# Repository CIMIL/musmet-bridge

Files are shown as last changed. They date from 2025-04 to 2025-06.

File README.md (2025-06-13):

# MUSMET MIDI Bridge
(**MUS**ical **MET**averse **MIDI** **Bridge**)

Hardware and software solution that lets you use your MIDI devices in a _**Musical Metaverse**_. Connect any class-compliant MIDI device and map its MIDI input into OSC messages. 
These OSC messages can then be sent to a VR/XR musical ecosystem (e.g., PatchWorld) or other compatible platforms.

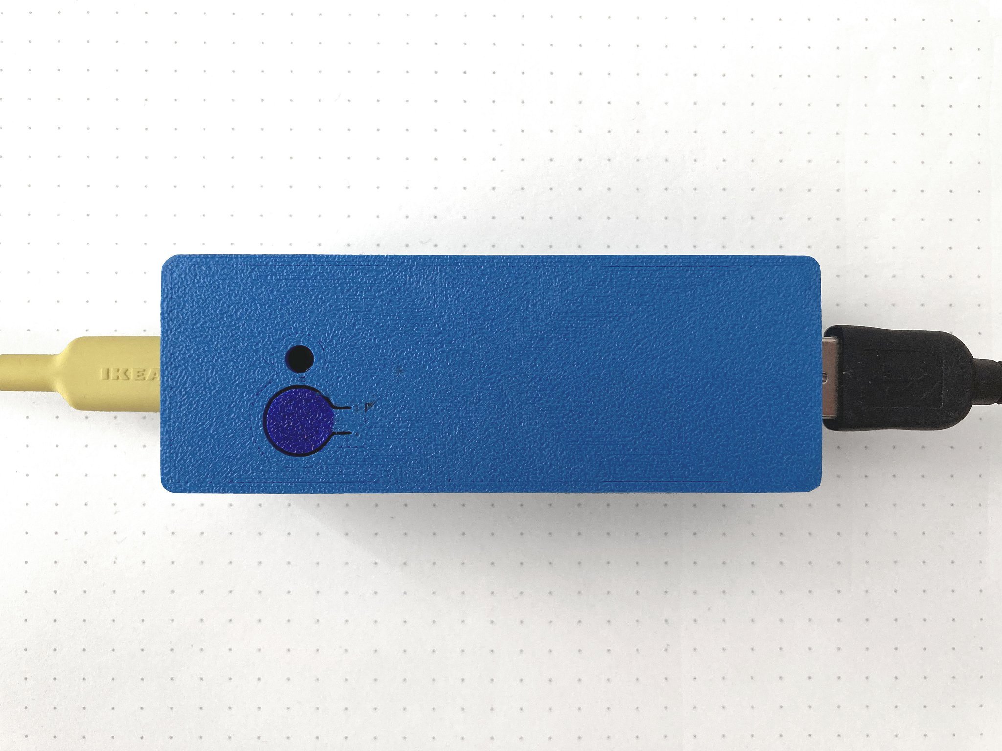
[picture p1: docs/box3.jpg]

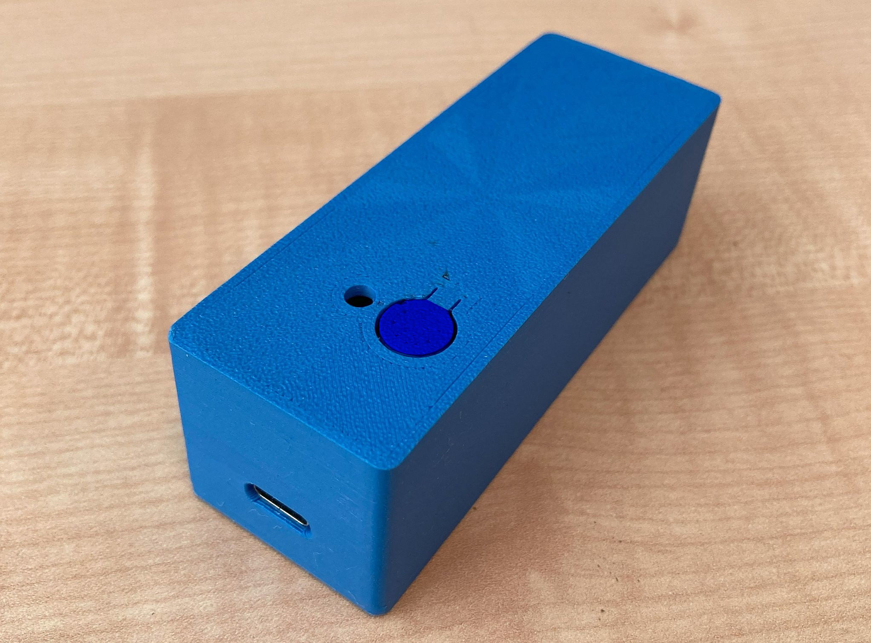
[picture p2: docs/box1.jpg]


## Features

- **MIDI Host Functionality**: Connect any class-compliant MIDI device to the Bridge.
- **OSC Message Mapping**: Translate MIDI input into OSC messages for seamless integration with PatchWorld or any other musical metaverse ecosystem.
- **Customizable Mapping**: Modify the MIDI-to-OSC mapping to suit your specific needs.

## Hardware
The Bridge's hardware consists of the following components:

- **Raspberry Pi Pico W**: Serves both as the MIDI host and as the OSC client, handling communication and processing.
- **USB-to-microUSB adapter**: USB-A cables are the most common.
- **Push button**: Used to reset the Pico W and enter WiFi config mode.
- **5V power supply**: Powers the Pico W and the connected MIDI device. The Pico W can't be powered through the USB port as it is used for MIDI communication. The power supply must be able to provide enough current for connected MIDI devices.

## Software

### Arduino Dependencies:
- [Arduino-Pico](https://github.com/earlephilhower/arduino-pico)
- [OSC](https://github.com/CNMAT/OSC)
- [EZ_USB_MIDI_HOST](https://github.com/rppicomidi/EZ_USB_MIDI_HOST)

### IDE Settings
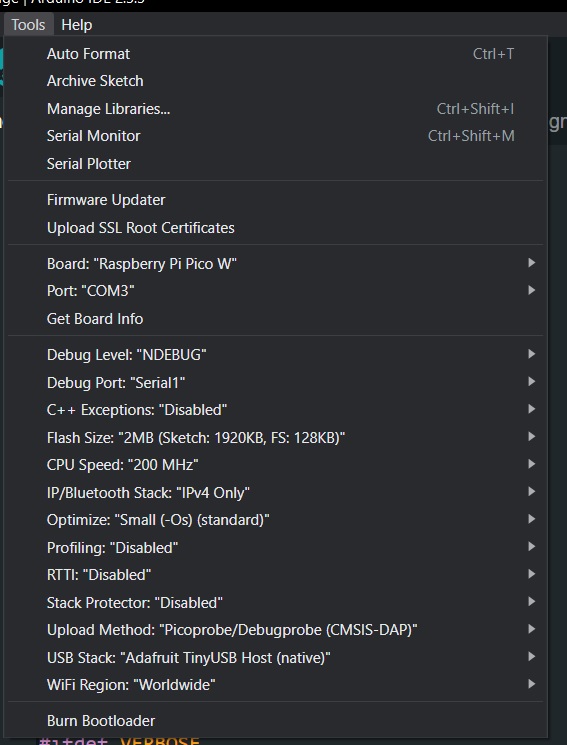
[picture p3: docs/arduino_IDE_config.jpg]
Arduino IDE Settings


## Debugging
To debug the project and view serial messages, you will need a DebugProbe (you can also use a Pico as a PicoProbe).

## MIDI-to-OSC Default Mapping Table
In this project we split the values of MIDI data1 and data2 into two distinct OSC messages. 
You can easily modify the code to customize the mapping.

| MIDI Message | Description | Mapped | First OSC Message | Second OSC Message |
|---|---|---|---|---|
| Note On | Trigger notes | ✅ | /ch{channel}note {pitch} | /ch{channel}nvalue {velocity} |
| Note Off | Release notes | ✅ | /ch{channel}noteoff {pitch}  | /ch{channel}noteoffvalue {velocity}|
| Control Changes (CC) | Modify parameters such as volume, pan, modulation  | ✅ | /ch{channel}cc {controller} | /ch{channel}ccvalue {value} |
| Pitch Bending | Adjust pitch dynamically | ✅ | /ch{channel}pitch {value}  | - |
| Aftertouch | Respond to pressure after keys are pressed | ✅ | /ch{channel}pressure {value} | - |
| Program Change | Switch instrument or patch presets | ❌ | - | - |
| System Exclusive (SysEx)  | Manufacturer-specific messages | ❌ | - | - |
| MIDI Time Code (MTC) | Synchronize playback with other devices | ❌ | - | - |
| Polyphonic Aftertouch | Individual pressure sensitivity for each note | ❌ | - | - |
| Song Select | Choose a specific song in a sequence | ❌ | - | - |
| Song Position Pointer | Indicate a specific position in a song | ❌ | - | - |
| System Real-Time Messages | Clock, start, stop, continue for synchronization | ❌ | - | - |

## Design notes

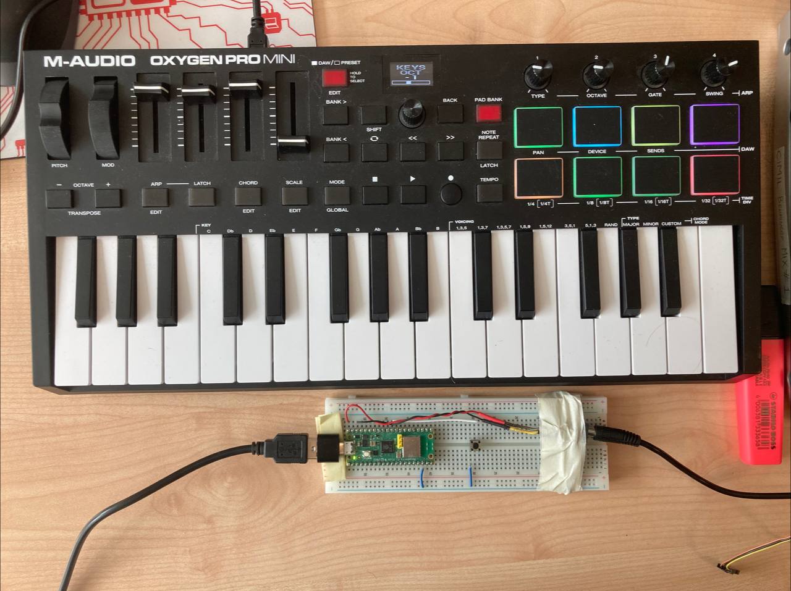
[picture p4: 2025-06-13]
docs/bridge_proto_keyboard.jpg

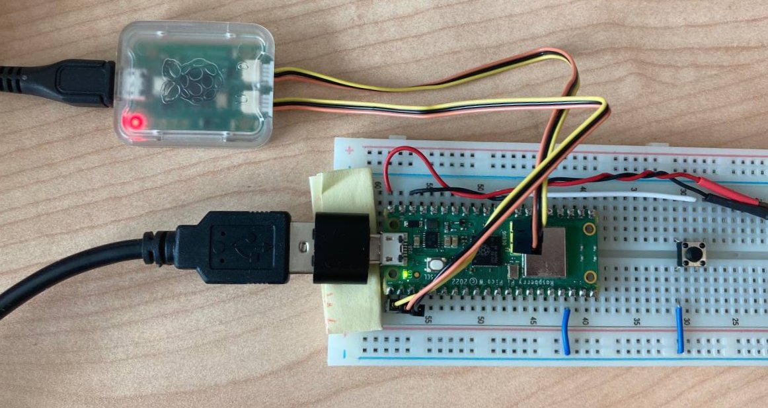
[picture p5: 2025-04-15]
docs/bridge_proto_with_probe.jpg

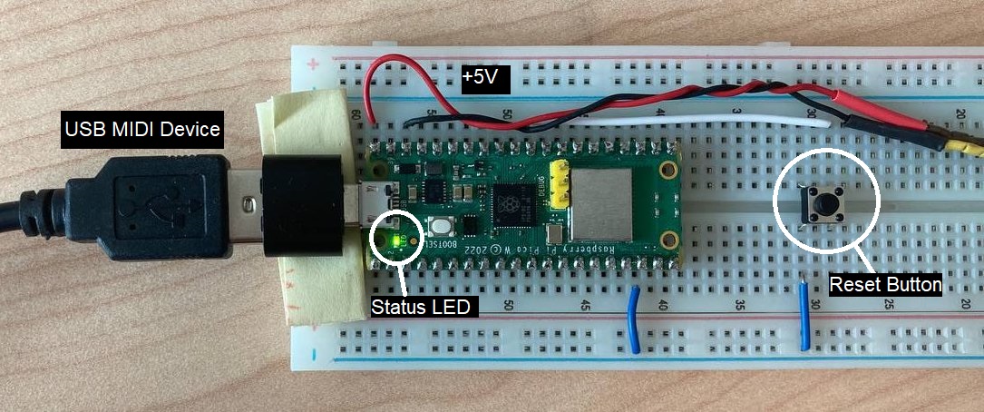
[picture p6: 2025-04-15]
docs/bridge_proto.jpg

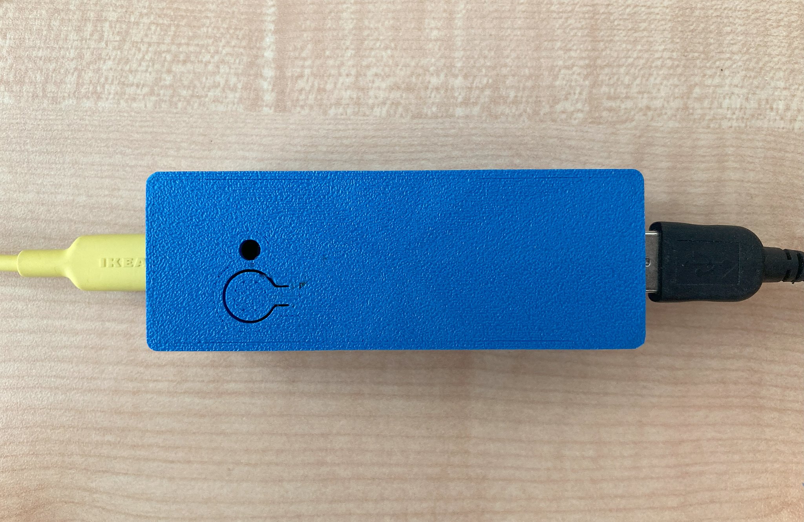
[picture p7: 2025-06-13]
docs/box2.jpg

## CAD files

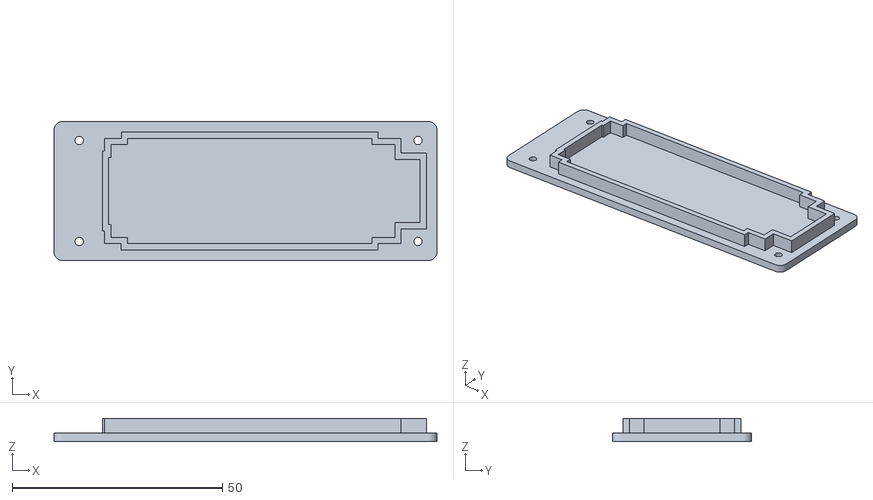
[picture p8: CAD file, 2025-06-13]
hardware/case/MUSMET_Lid.stl
91.0 x 33.0 x 5.50

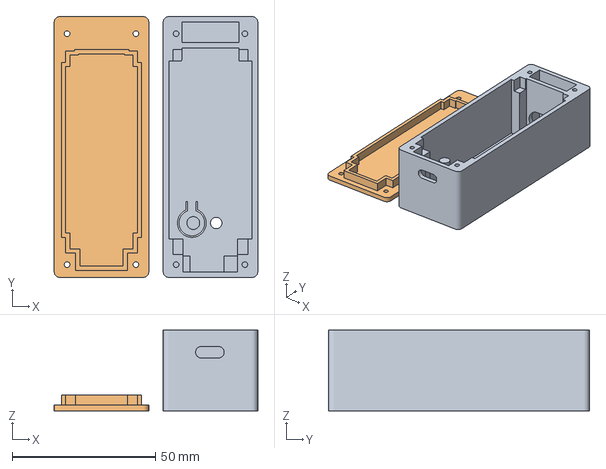
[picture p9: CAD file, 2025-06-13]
hardware/case/MusmetBox.3mf
71.0 x 91.0 x 28.1 mm
MUSMET_BoxTopv2.stl
MUSMET_Lid.stl

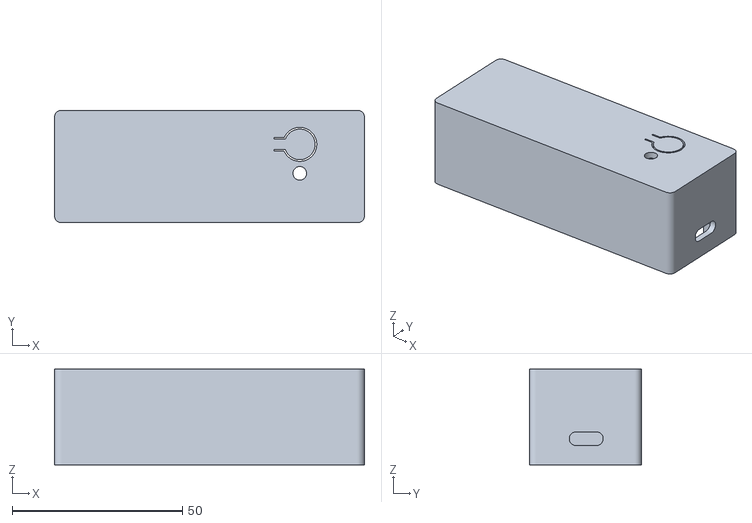
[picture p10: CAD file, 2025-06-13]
hardware/case/MUSMET_BoxTopv2.stl
91.0 x 33.0 x 28.1

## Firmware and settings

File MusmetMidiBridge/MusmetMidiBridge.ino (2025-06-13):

#include <Arduino.h>

#define UPLOAD_METHOD_DEBUGPROBE
#define VERBOSE 1 // define verbosity : {0=No_verbose, 1=verbose, 2=very_verbose}

#include "utils.h"   
#include "twomode.h"

TwoMode tmcontroller(Utils::LED_PIN);

#include "oscmode.h"
#include "configmode.h"

enum Modes {
  NONE = 0,
  CONFIG_MODE = 1,
  OSC_MODE = 2
};
short mode;


OscMode oscmode;
ConfigMode configmode;

void setup() {
  // Initialize serial connection
#ifdef VERBOSE
  DEBUG_SERIAL.begin(115200);
#endif
  
  pinMode(Utils::LED_PIN, OUTPUT);

#if (VERBOSE > 0)
  while (!DEBUG_SERIAL) yield();
  DEBUG_SERIAL.println("\nSerial Initialized!");
#endif

  tmcontroller.init();

  mode = tmcontroller.getMode();
#if (VERBOSE > 0)
  DEBUG_SERIAL.print("Starting Mode ");
  DEBUG_SERIAL.println(mode);
#endif

  if (mode == OSC_MODE)
  {
    oscmode.setup();
  } else if (mode == CONFIG_MODE) {
    configmode.setup();
  } else {

  }
}

void loop() {
  if (mode == OSC_MODE)
  {
    oscmode.loop();
  } else if (mode == CONFIG_MODE) {
    configmode.loop();
  } else {

  }
}

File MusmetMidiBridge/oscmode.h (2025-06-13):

#ifndef _OSCMODE_H
#define _OSCMODE_H

#if !defined(USE_TINYUSB_HOST) || !defined(USE_TINYUSB)
#error "Please use the Menu to select Tools->USB Stack: Adafruit TinyUSB Host"
#else
#warning "All Serial Monitor Output is on DEBUG_SERIAL."
#endif

// USB MIDI Host
#include <EZ_USB_MIDI_HOST.h>

// WiFi/OSC Headers
#include <WiFi.h>
#include <AsyncUDP.h>
#include <OSCMessage.h>
// Read WiFi config from the filesystem
#include "utils.h"


// WIFI Config (to be read from LittleFS)
char cconfigSSID[64], cconfigPWD[64], cOutIP[20], cOutPort[20];

// UDP Client object
AsyncUDP udp;
AsyncUDPMessage udpMessage;

// USB Host object
Adafruit_USBH_Host USBHost;
USING_NAMESPACE_MIDI
USING_NAMESPACE_EZ_USB_MIDI_HOST

// Instantiate the EZ_USB_MIDI_HOST object with name "usbhMIDI" using the default "MidiHostSettingsDefault" configuration
RPPICOMIDI_EZ_USB_MIDI_HOST_INSTANCE(usbhMIDI, MidiHostSettingsDefault)

static uint8_t connectedDevAddrs[RPPICOMIDI_TUH_MIDI_MAX_DEV];
static uint8_t numConnectedDevices = 0;


// Send an OSC message with the given address and arguments 
template <typename... Args>
inline void sendOSCMessage(const char* address, Args... args) {
  OSCMessage msg(address); // Create OSC message
  (msg.add(args), ...);  // Fold expression to add all arguments
  msg.send(udpMessage);  // Send OSC message to UDPMessage buffer
  udp.send(udpMessage);  // Send the message over UDP
  msg.empty();           // Free space occupied by message
  udpMessage.flush();    
}

/* MIDI IN MESSAGE MAPPING */
static void onMidiError(int8_t errCode) {
#if (VERBOSE > 0)
  DEBUG_SERIAL.printf("MIDI Errors: %s %s %s\r\n", (errCode & (1UL << ErrorParse)) ? "Parse" : "",
                      (errCode & (1UL << ErrorActiveSensingTimeout)) ? "Active Sensing Timeout" : "",
                      (errCode & (1UL << WarningSplitSysEx)) ? "Split SysEx" : "");
#endif
}

static void onNoteOff(Channel channel, byte note, byte velocity) {
#if (VERBOSE > 0)
  DEBUG_SERIAL.printf("C%u: Note off#%u v=%u\r\n", channel, note, velocity);
#endif
  digitalWrite(Utils::LED_PIN, LOW);
  char address[12];
  snprintf(address, sizeof(address), "/ch%dnoteoff", (int)channel);
  sendOSCMessage(address, note);  // /ch<channel>noteoff (<note>,)
  snprintf(address, sizeof(address), "/ch%dnoteoffvalue", (int)channel);
  sendOSCMessage(address, velocity);  // /ch<channel>noteoffvalue (<velocity>,)
}

static void onNoteOn(Channel channel, byte note, byte velocity) {
#if (VERBOSE > 0)
  DEBUG_SERIAL.printf("C%u: Note on#%u v=%u\r\n", channel, note, velocity);
#endif
  digitalWrite(Utils::LED_PIN, LOW);
  char address[12];
  snprintf(address, sizeof(address), "/ch%dnote", (int)channel);
  sendOSCMessage(address, note);  // /ch<channel>note (<note>,)
  snprintf(address, sizeof(address), "/ch%dnvalue", (int)channel);
  sendOSCMessage(address, velocity);  // /ch<channel>nvalue (<velocity>,)
}

static void onControlChange(Channel channel, byte controller, byte value) {
#if (VERBOSE > 0)
  DEBUG_SERIAL.printf("C%u: CC#%u=%u\r\n", channel, controller, value);
#endif  
  digitalWrite(Utils::LED_PIN, LOW);
  char address[12];
  snprintf(address, sizeof(address), "/ch%dcc", (int)channel);
  sendOSCMessage(address, controller);  // /ch<channel>cc (<controller>,)
  snprintf(address, sizeof(address), "/ch%dccvalue", (int)channel);
  sendOSCMessage(address, value);  // /ch<channel>ccvalue (<value>,)
}

static void onProgramChange(Channel channel, byte program) {
#if (VERBOSE > 0)
  DEBUG_SERIAL.printf("C%u: Prog=%u\r\n", channel, program);
#endif
}

static void onPitchBend(Channel channel, int value) {
#if (VERBOSE > 0)
  DEBUG_SERIAL.printf("C%u: PB=%d\r\n", channel, value);
#endif
  char address[12];
  snprintf(address, sizeof(address), "/ch%dpitch", (int)channel);
  sendOSCMessage(address, value);  // /ch<channel>pitch (<value>,)
}

static void onAftertouch(Channel channel, byte value) {
#if (VERBOSE > 0)
  DEBUG_SERIAL.printf("C%u: AT=%u\r\n", channel, value);
#endif
  char address[12];
  snprintf(address, sizeof(address), "/after%d", (int)channel);
  sendOSCMessage(address, value); // /after<channel> (<value>,)
}

static void onPolyphonicAftertouch(Channel channel, byte note, byte amount) {
#if (VERBOSE > 0)
  DEBUG_SERIAL.printf("C%u: PAT#%u=%u\r\n", channel, note, amount);
#endif
}

static void onSysEx(byte* array, unsigned size) {
#if (VERBOSE > 1)
  DEBUG_SERIAL.printf("SysEx:\r\n");
#endif
  unsigned multipleOf8 = size / 8;
  unsigned remOf8 = size % 8;
  for (unsigned idx = 0; idx < multipleOf8; idx++) {
#if (VERBOSE > 1)
    for (unsigned jdx = 0; jdx < 8; jdx++) {
      DEBUG_SERIAL.printf("%02x ", *array++);
    }
    DEBUG_SERIAL.printf("\r\n");
#endif
  }
#if (VERBOSE > 1)
  for (unsigned idx = 0; idx < remOf8; idx++) {
    DEBUG_SERIAL.printf("%02x ", *array++);
  }
  DEBUG_SERIAL.printf("\r\n");
#endif
}

static void onSMPTEqf(byte data) {
  uint8_t type = (data >> 4) & 0xF;
  data &= 0xF;
  static const char* fps[4] = { "24", "25", "30DF", "30ND" };
#if (VERBOSE > 1)
  switch (type) {
    case 0: DEBUG_SERIAL.printf("SMPTE FRM LS %u \r\n", data); break;
    case 1: DEBUG_SERIAL.printf("SMPTE FRM MS %u \r\n", data); break;
    case 2: DEBUG_SERIAL.printf("SMPTE SEC LS %u \r\n", data); break;
    case 3: DEBUG_SERIAL.printf("SMPTE SEC MS %u \r\n", data); break;
    case 4: DEBUG_SERIAL.printf("SMPTE MIN LS %u \r\n", data); break;
    case 5: DEBUG_SERIAL.printf("SMPTE MIN MS %u \r\n", data); break;
    case 6: DEBUG_SERIAL.printf("SMPTE HR LS %u \r\n", data); break;
    case 7: DEBUG_SERIAL.printf("SMPTE HR MS %u FPS:%s\r\n", data & 0x1, fps[(data >> 1) & 3]); break;
    default:DEBUG_SERIAL.printf("invalid SMPTE data byte %u\r\n", data); break;
  }
#endif
}

static void onSongPosition(unsigned beats) {
#if (VERBOSE > 0)
  DEBUG_SERIAL.printf("SongP=%u\r\n", beats);
#endif
}

static void onSongSelect(byte songnumber) {
#if (VERBOSE > 0)
  DEBUG_SERIAL.printf("SongS#%u\r\n", songnumber);
#endif
}

static void onTuneRequest() {
#if (VERBOSE > 0)
  DEBUG_SERIAL.printf("Tune\r\n");
#endif
}

static void onMidiClock() {
#if (VERBOSE > 1)
  DEBUG_SERIAL.printf("Clock\r\n");
#endif
}

static void onMidiStart() {
#if (VERBOSE > 0)
  DEBUG_SERIAL.printf("Start\r\n");
#endif
}

static void onMidiContinue() {
#if (VERBOSE > 0)
  DEBUG_SERIAL.printf("Cont\r\n");
#endif
}

static void onMidiStop() {
#if (VERBOSE > 0)
  DEBUG_SERIAL.printf("Stop\r\n");
#endif
}

static void onActiveSense() {
#if (VERBOSE > 1)
  DEBUG_SERIAL.printf("ASen\r\n");
#endif
}

static void onSystemReset() {
#if (VERBOSE > 0)
  DEBUG_SERIAL.printf("SysRst\r\n");
#endif
}

static void onMidiTick() {
#if (VERBOSE > 1)
  DEBUG_SERIAL.printf("Tick\r\n");
#endif
}
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

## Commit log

2025-04-09 Test MIDI host. Print incoming messages into Serial
2025-04-09 Add mapping to pitch bending, control changes and aftertouch
2025-04-10 Fix soft access point + Add DEBUG_SERIAL
    [midi2osc.ino, wifi_soft_access_point.ino]
2025-04-10 Add DNS, but I think we can avoid using it
    [wifi_soft_access_point.ino]
2025-05-23 Update status LED blinking and debug verbosity
2025-06-04 new case and partial questionnaires
    [MUSMET_BoxTopv2.stl, MUSMET_Lid.stl, MusmetBox.3mf]
2025-06-13 Added DNS functionality. Redirect to "bridge.conf" instead of having to manually enter pico IP. Captive portal should open automatically.
2025-06-19 add plots
    [Responses - MERGE_Room1_Bridge.csv, Responses - MERGE_Room1_Laptop.csv, Responses - MERGE_Room2_Bridge.csv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]
2025-06-19 add sus score and result tables
    [Responses - MERGE_Room1_Bridge.csv, Responses - MERGE_Room1_Laptop.csv, Responses - MERGE_Room2_Bridge.csv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]
2025-06-20 add user3 and 4
    [Video Analyisis - Timings_Bridge.csv, Video Analyisis - Timings_Laptop.csv]
2025-07-01 update data
    [Responses - MERGE_Room1_Bridge.csv, Responses - MERGE_Room1_Laptop.csv, Responses - MERGE_Room2_Bridge.csv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]
